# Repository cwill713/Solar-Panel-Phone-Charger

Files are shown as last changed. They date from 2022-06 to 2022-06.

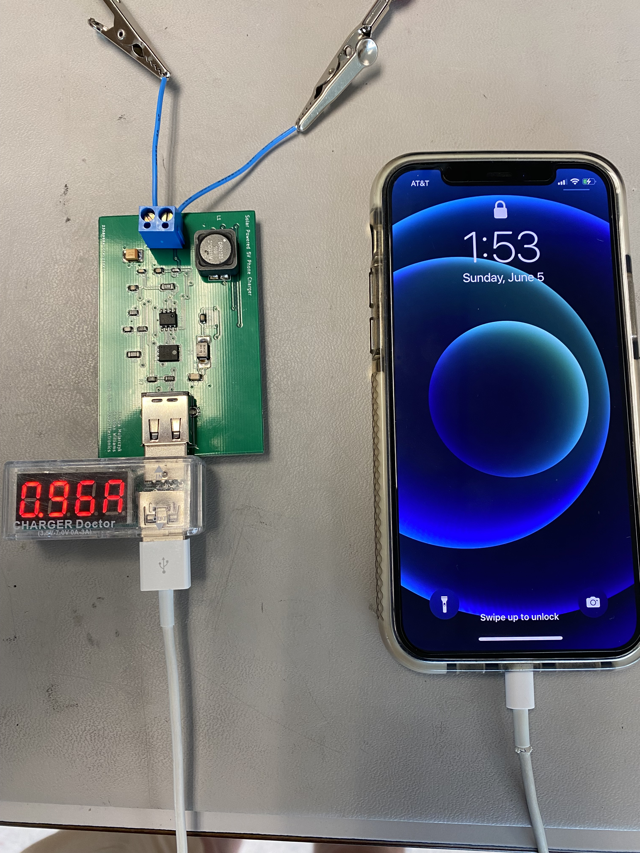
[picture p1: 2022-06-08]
Pictures/Output current to iphone.jpg

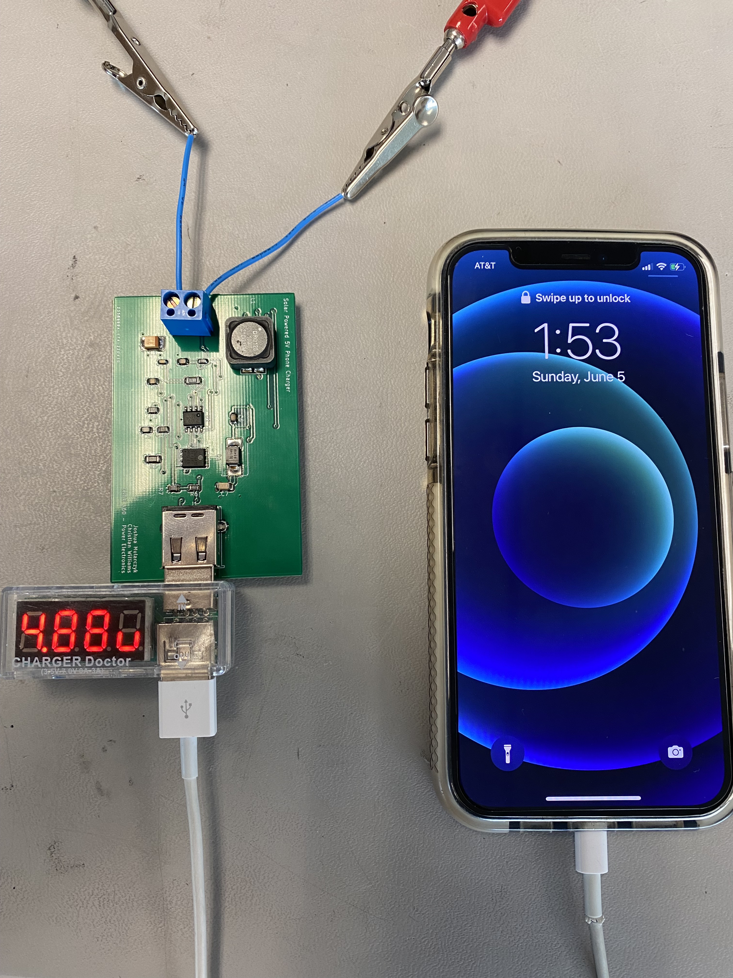
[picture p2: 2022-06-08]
Pictures/Output Voltage to iphone.jpg

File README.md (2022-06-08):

# Solar Smartphone Charger

This is the the project, assigned by [Dr. Rob Frohne](https://github.com/frohro), that [Joshua Mularczyk](https://github.com/JoshuaMularczyk) and I designed for our Power Electronics class. This project used our knowledge of power efficiency and stepping down voltage along with our knowledge of KiCAD and LTSpice to create our own portable solar phone charges. 

## Design Objectives:
- Output 5V from a higher input voltage
- Draw 1A at the output
- Inexpensive ($20-$30 Budget)
- AS efficient as possible

## Overview

Capture

Josh and I wanted to design a solar phone charger because we thought of the potential use of people who spend a lot of time outside. We also knew that Apple products need certain specifications to charge as oppose to Andriod products so we set out to figure out how to make our charger work for both.

The first simulation/schematic of our project allowed us to get the desired outputs, but we found that it was not very efficient, so we decided to redesign our board and end up with a new string of designs

The heart of our circuit is the [LM3478](https://www.ti.com/lit/ds/symlink/lm3478.pdf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) which is a high-efficiency low-side n-channel controller. This allows us to regulate any voltage between 2.39 and 40V that could come from our 10W solar panels

## Rev 7 Design

schematic2

This is the most recent KiCad schematic for our circuit design. Josh used the Texas Instrument [Webench Power Designer](https://www.ti.com/design-resources/design-tools-simulation/webench-power-designer.html) to generate this step-down circuit. The design specified a 5V to 12V input voltage based on the likely solar panel outputs. We also specified the a maximum of 1A should be be able to be drawn from our circuit.

## Rev 7 Simulation
sim
This is the complete simulation of our circuit. We can see here that at around 7ms, the output voltage of circuit is 5V

### Voltage Outputs (5V 2.7V 2V)
ThreeOutputVoltages

This is the simulation of the voltage dividers that shows the voltage going to our USB pins. V+, D+, and D-. This will be talked about more in the testing section.

### Input and Output Current
currentsim

This simulations shows us that we achieved the low input voltage that we need. The 5 Ohm resistor allowed us to simulate the current our phone would draw from the circuit. The output current of 1A will allow us to power our phone with 5W.

## Rev 7 PCB Design
pcb2

This is the PCB design of the board we sourced from [JLCPCB](https://jlcpcb.com/VGS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),

## Rev 6 Testing


Josh and I each constructed a our own boards and tested them. When testing the boards with a 0-18V 1A power supply, we found that the boards could charge Ti-84 calculators and Andriod phones, but not an iPhone. To see if we couldn't draw enough current from the power supply, we connected our board to 24V 3A power supply and saw the same results. After we performed some research, Josh found that we needed voltage across the D+ and D- pins, 2.7 and 2V respectivly. To achieve this, we created a votalde dividers using through-hole resistors and soldered them to the back of the boards. We then tested the boards and found that we were able to succesfully charge our iPhones.




After we tested the boards in the lab, we connected our boards to our solar panels and tested them outside. We found that we were getting around 4.8V and .96A at the output which gave us 4.61W at the output. 

## Rev 6 Results
The image on the left shows the voltage being supplied to the iPhone through the 24V 4A power suplies. The image on the right shows the current being drawn by the iPhone.



More images are avaialble in the [pictures](https://github.com/cwill713/Solar-Panel-Phone-Charger/tree/main/Pictures) folder. The video of testing made by Josh is availabel [here](https://youtu.be/SS7m2UqrDPg).

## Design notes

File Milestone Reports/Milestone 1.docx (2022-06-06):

Joshua Mularczyk and Christian Williams

ENGR 460

Milestone 1

4 April 2022

Project Definition

Project: Solar powered phone charger

Stretch Goal: Make it a wireless charger

Definition:

For our project this quarter, we have decided to design power electronics to use solar power to charge a smartphone. This will be done using solar panels that will provide charge to a external rechargeable battery (maybe 2 AA’s?) which will then run through circuitry that has some type of switch that shuts off the charging when the maximum voltage has been reached and circuitry to allow the power to pass from the batteries through a USB port so that a smart phone can be plugged in. If time allows, a casing can be designed for the circuitry using 3D printing for a final portable product.

References that sparked idea:

https://www.youtube.com/watch?v=OyslcihUtzQ

- Youtube video explaining how to create a DC to DC Boost Converter

https://www.instructables.com/Wireless-Solar-Charger/

- Project using solar panels to create a wireless charger for a smartphone

https://www.engineeringforchange.org/news/how-to-build-a-solar-powered-usb-charger-for-phones-and-other-small-devices/

- Shows the process of designing a similar solar powered phone charger

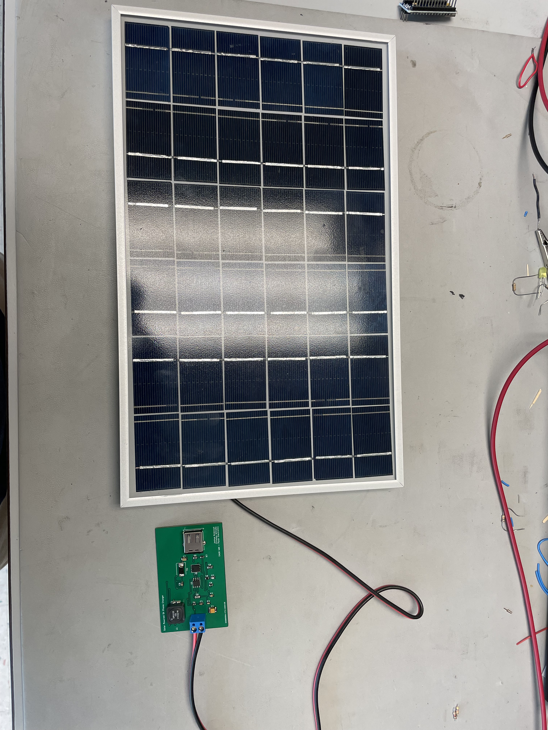
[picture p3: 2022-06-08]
Pictures/solar panel.jpg

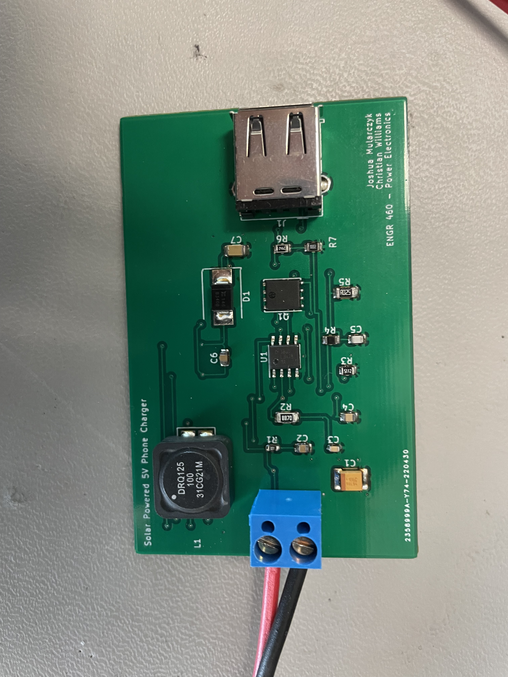
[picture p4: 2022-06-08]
Pictures/circuit board.jpg

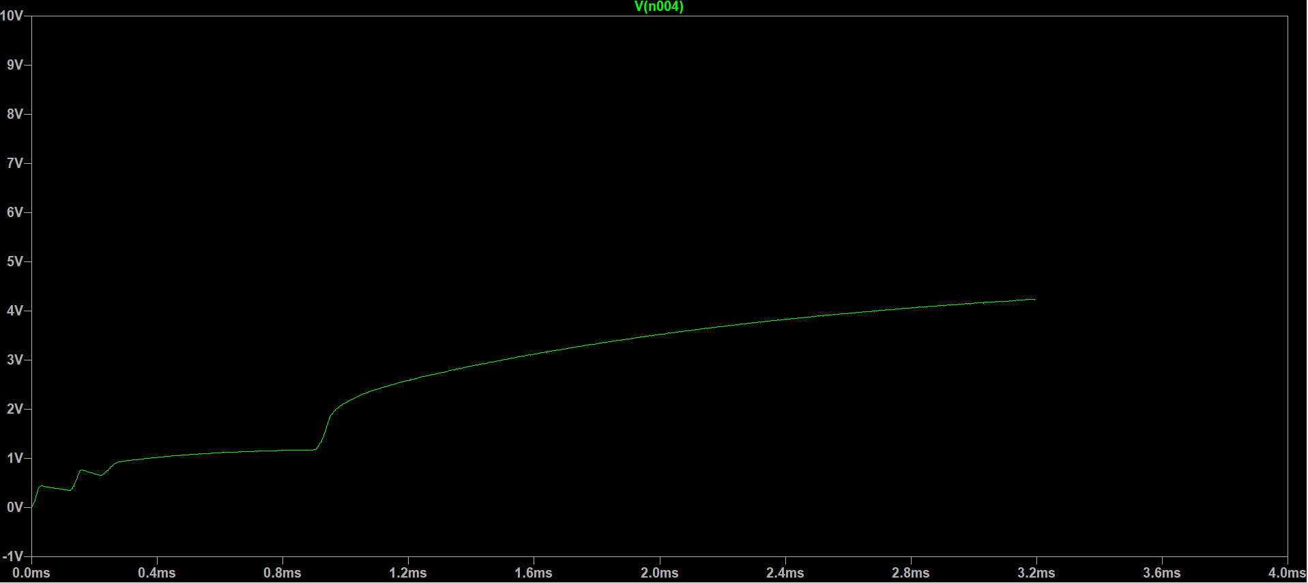
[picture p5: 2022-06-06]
Simulations/Pictures of Output Voltage/LoadResistorSimClose.PNG

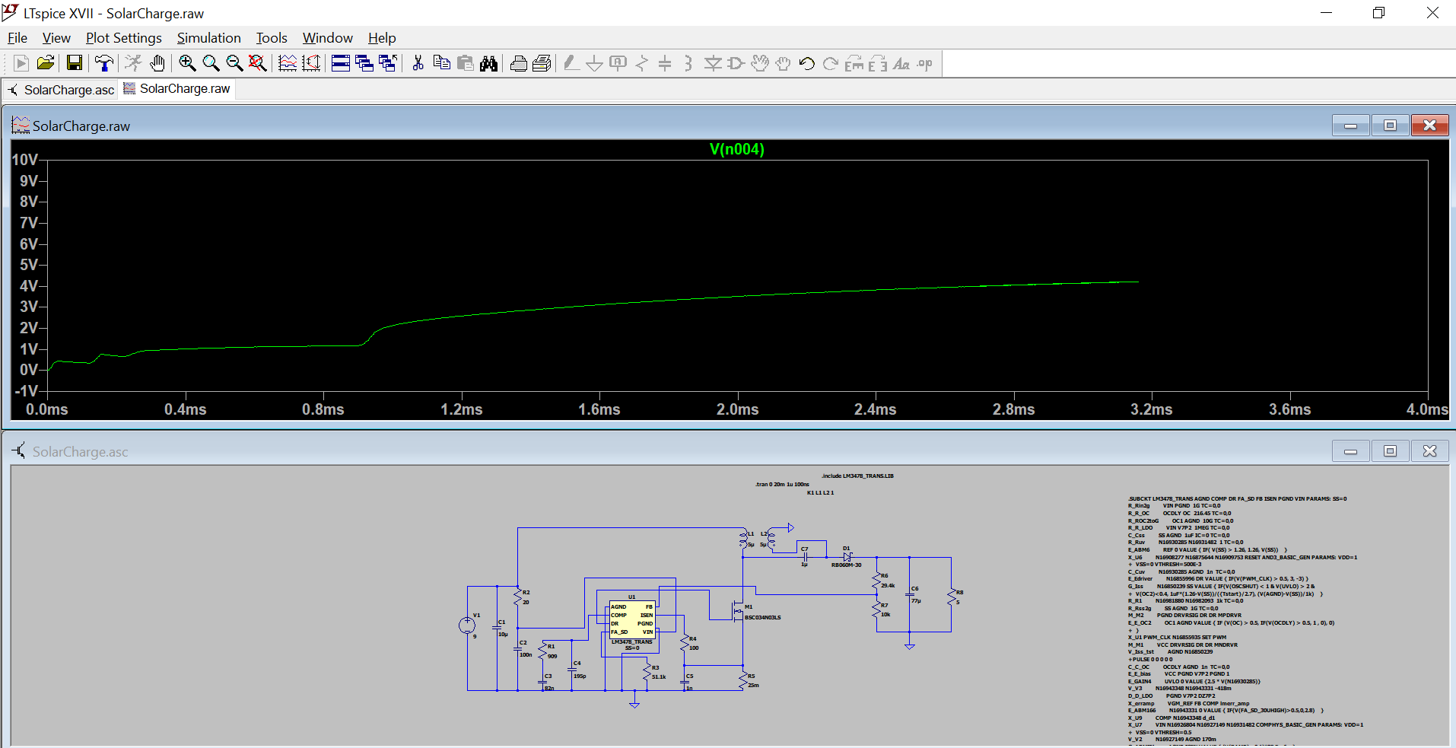
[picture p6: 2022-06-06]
Simulations/Pictures of Output Voltage/loadResistorSim.PNG

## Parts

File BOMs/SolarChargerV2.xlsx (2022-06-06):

Id | Label | Footprint | Amount | Value | Price | Supplier and ref
1 | Le | DRQ | 1 | 10u | $1.81 | https://www.digikey.com/en/products/detail/eaton-electronics-division/DRQ125-100-R/667233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
2 | C7 | Capacitor_SMD:C_1206_3216Metric | 1 | 47u | $0.74 | https://www.digikey.com/en/products/detail/murata-electronics/GRM31CR61A476KE15L/4359666
3 | C1 | Capacitor_SMD:C_1812_4532Metric | 1 | 10u | $0.45 | https://www.digikey.com/en/products/detail/kyocera-avx/TPSB106K016R0800/678477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
4 | C5 | Capacitor_SMD:C_0805_2012Metric | 1 | 1n | $0.10 | https://www.digikey.com/en/products/detail/walsin-technology-corporation/0805N102J500CT/9355088
5 | C3 | Capacitor_SMD:C_0603_1608Metric | 1 | 82n | $0.14 | https://www.digikey.com/en/products/detail/kyocera-avx/0603YC823KAT2A/563348
6 | C2 | Capacitor_SMD:C_0805_2012Metric | 1 | 100n | $0.10 | https://www.digikey.com/en/products/detail/w%C3%BCrth-elektronik/885012207045/5453900
7 | C4 | Capacitor_SMD:C_0805_2012Metric | 1 | 200p | $0.15 | https://www.digikey.com/en/products/detail/yageo/CC0805KRX7R9BB201/5884236
8 | C6 | Capacitor_SMD:C_0805_2012Metric | 1 | 1u | $0.19 | https://www.digikey.com/en/products/detail/murata-electronics/GRM21BR71C105MA01L/586691
9 | J1 | USB_A_Molex_67643_Horizontal | 1 | USB_A | $1.66 | https://www.digikey.com/en/products/detail/molex/0676430910/917619
10 | D1 | Diode_SMD:D_SMC | 1 | B340 | $0.54 | https://www.digikey.com/en/products/detail/diodes-incorporated/B340B-13-F/768869
11 | U1 | SOIC-8_3.9x4.9mm_P1.27mm | 1 | LM3478MA_NOPB | $2.95 | https://www.digikey.com/en/products/detail/texas-instruments/LM3478MA-NOPB/2682777
12 | Q1 | TDSON-8-1 | 1 | CSD16410Q5A | $1.01 | https://www.digikey.com/en/products/detail/texas-instruments/CSD16410Q5A/2038309
13 | R6 | Resistor_SMD:R_0805_2012Metric | 1 | 29.4k | $0.10 | https://www.digikey.com/en/products/detail/panasonic-electronic-components/ERJ-6ENF2942V/111566
14 | R4 | Resistor_SMD:R_0805_2012Metric | 1 | 100 | $1.63 | https://www.digikey.com/en/products/detail/vishay-dale/M55342K06B100DRS3/2941801
15 | R3 | Resistor_SMD:R_0805_2012Metric | 1 | 51.1k | $0.10 | https://www.digikey.com/en/products/detail/yageo/RC0805FR-0751K1L/728015
16 | R1 | Resistor_SMD:R_0603_1608Metric | 1 | 20 | $0.10 | https://www.digikey.com/en/products/detail/yageo/RC0603FR-0720RL/727039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
17 | R7 | Resistor_SMD:R_0805_2012Metric | 1 | 10k | $0.10 | https://www.digikey.com/en/products/detail/stackpole-electronics-inc/RNCP0805FTD10K0/2240262
18 | R5 | Resistor_SMD:R_1206_3216Metric | 1 | 25m | $0.49 | https://www.digikey.com/en/products/detail/stackpole-electronics-inc/CSR1206FK25L0/1646093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
19 | R2 | Resistor_SMD:R_1206_3216Metric | 1 | 887 | $0.20 | https://www.digikey.com/en/products/detail/panasonic-electronic-components/ERJ-8ENF8870V/88853
20 | SC1 | SIP-2 | 1 | Solar_Cell | $17.99 | amazon.com/dp/B00OZC19AY/ref=emc_bcc_2_i?th=1 (https://www.amazon.com/Treedix-Polysilicon-Polycrystalline-Encapsulated-Waterproof/dp/B0834MQDT8)
 |  |  |  | Total Cost | $30.55 | cart | https://www.digikey.com/short/1jf4t9wm

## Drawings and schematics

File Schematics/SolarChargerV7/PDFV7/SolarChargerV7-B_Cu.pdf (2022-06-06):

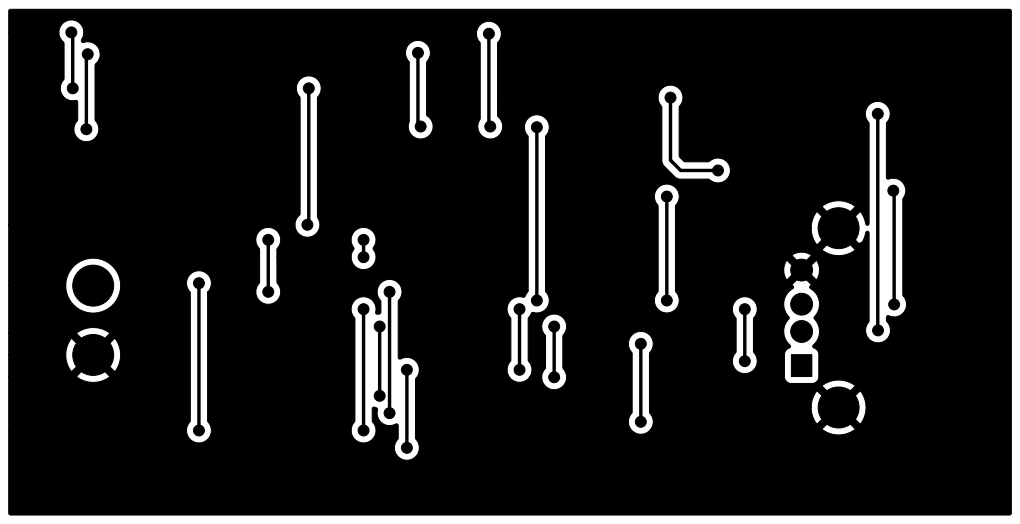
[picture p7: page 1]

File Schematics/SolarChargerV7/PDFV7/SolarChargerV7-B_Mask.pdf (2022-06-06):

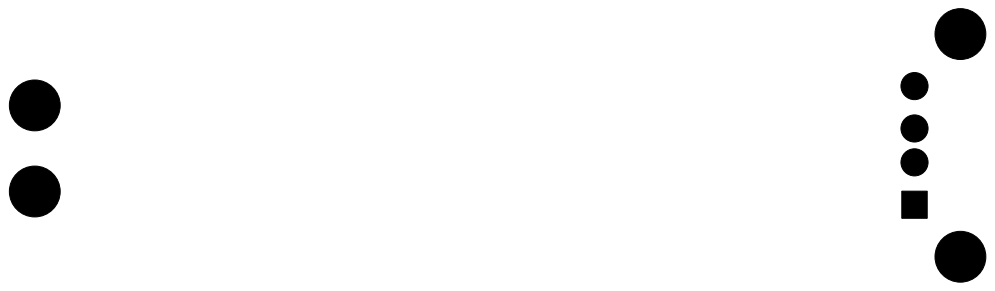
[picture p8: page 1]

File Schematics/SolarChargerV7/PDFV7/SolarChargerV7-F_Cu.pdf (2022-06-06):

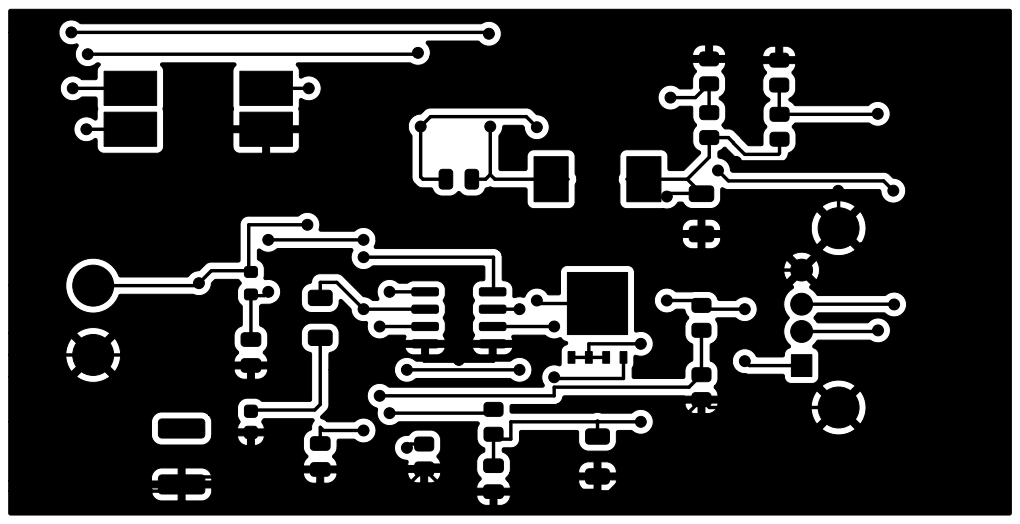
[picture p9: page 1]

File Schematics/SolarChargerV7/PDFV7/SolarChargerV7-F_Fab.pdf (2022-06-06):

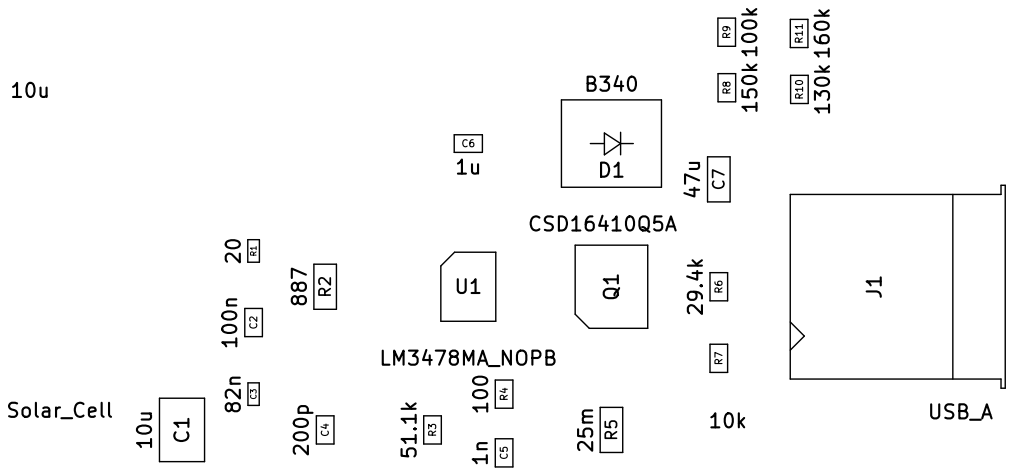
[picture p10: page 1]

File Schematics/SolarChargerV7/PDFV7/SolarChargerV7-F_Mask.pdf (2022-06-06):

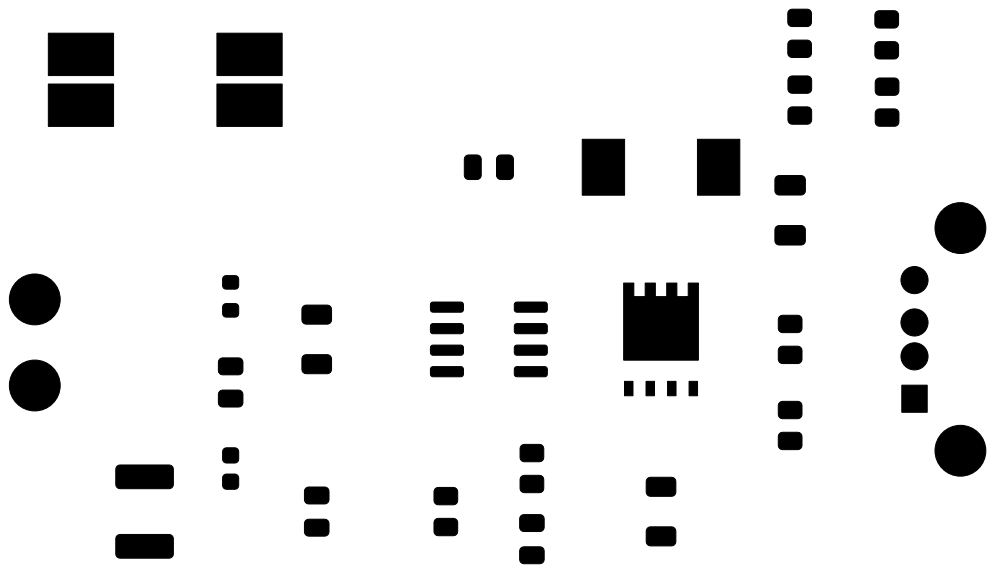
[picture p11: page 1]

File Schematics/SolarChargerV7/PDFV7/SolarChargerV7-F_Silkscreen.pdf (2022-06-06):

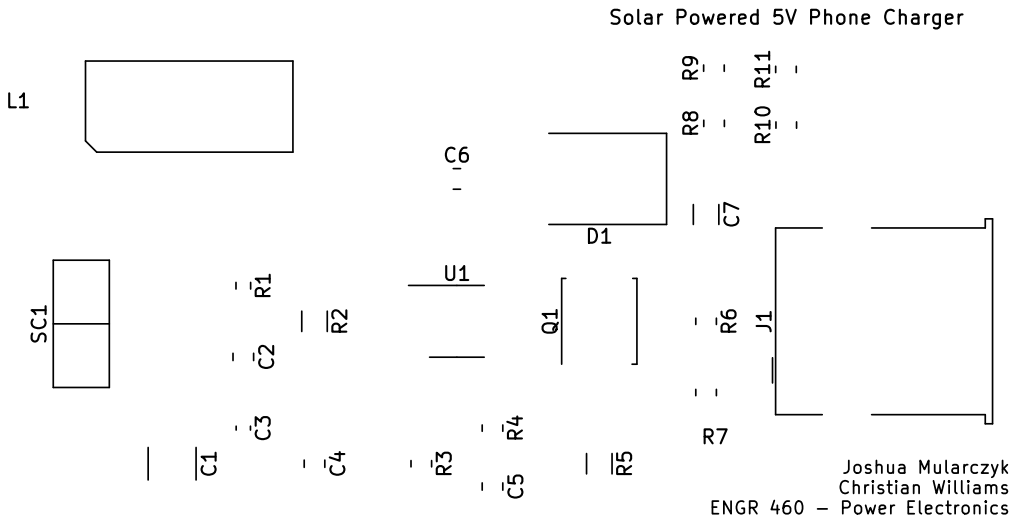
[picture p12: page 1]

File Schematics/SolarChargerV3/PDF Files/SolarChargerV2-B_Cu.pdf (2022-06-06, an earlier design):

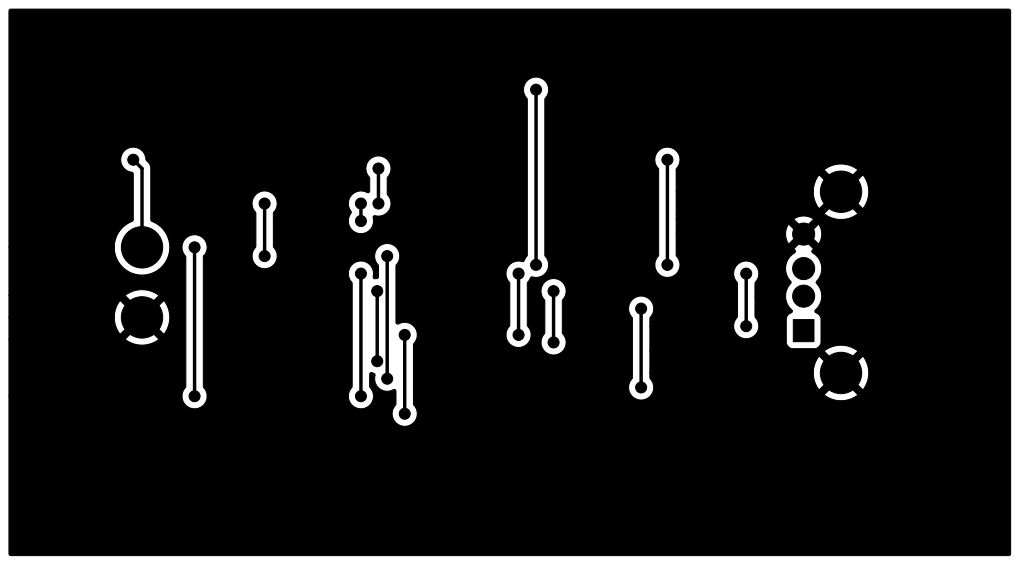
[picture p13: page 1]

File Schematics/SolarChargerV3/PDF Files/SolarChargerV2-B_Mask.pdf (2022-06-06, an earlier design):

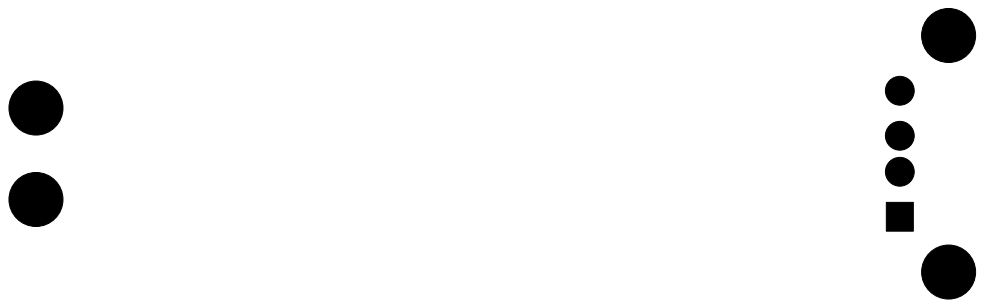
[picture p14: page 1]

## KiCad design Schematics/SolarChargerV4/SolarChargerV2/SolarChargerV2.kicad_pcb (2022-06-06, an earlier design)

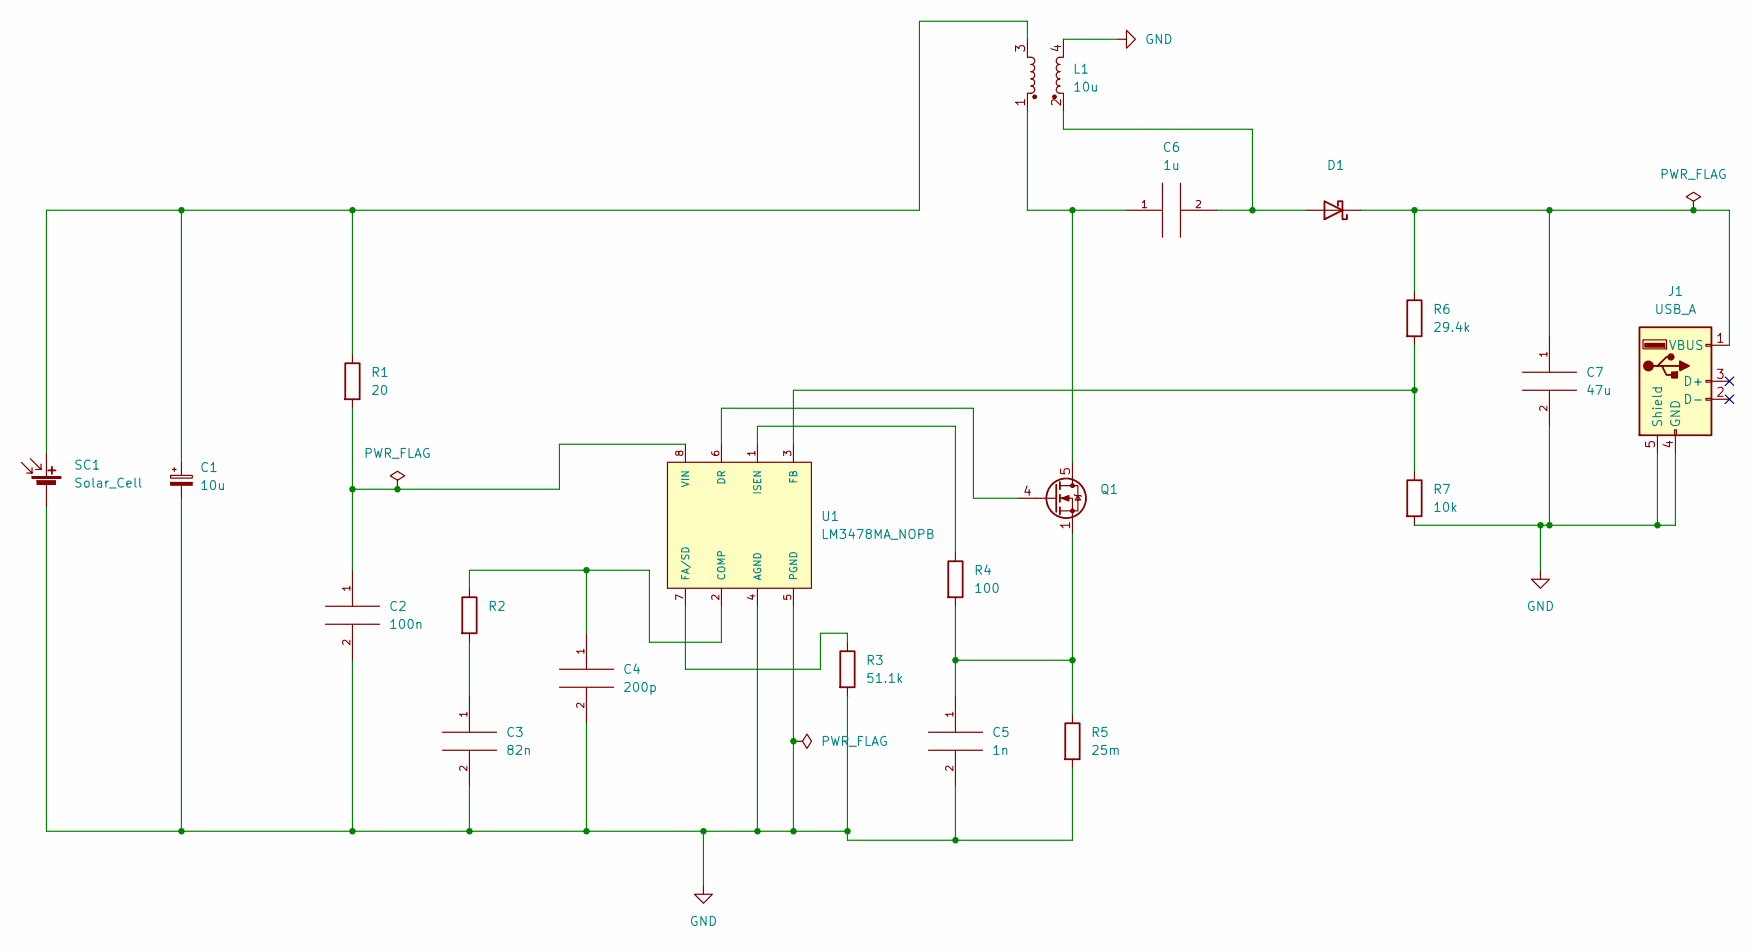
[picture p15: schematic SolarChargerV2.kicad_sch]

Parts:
C1: 10u; CP_Elec_3x5.3
C2: 100n; C_0603_1608Metric_Pad1.08x0.95mm_HandSolder
C3: 82n; C_0603_1608Metric_Pad1.08x0.95mm_HandSolder
C4: 200p; C_1812_4532Metric_Pad1.57x3.40mm_HandSolder
C5: 1n; C_0603_1608Metric_Pad1.08x0.95mm_HandSolder
C6: 1u; C_2220_5650Metric_Pad1.97x5.40mm_HandSolder
C7: 47u; CP_Elec_3x5.3
D1: (no value)
J1: USB_A; USB_A_Molex_67643_Horizontal
L1: 10u; DRQ
Q1: (no value)
R1: 20; R_0603_1608Metric_Pad0.98x0.95mm_HandSolder
R2: (no value)
R3: 51.1k; R_0603_1608Metric_Pad0.98x0.95mm_HandSolder
R4: 100; R_0603_1608Metric_Pad0.98x0.95mm_HandSolder
R5: 25m; R_2816_7142Metric_Pad3.20x4.45mm_HandSolder
R6: 29.4k; R_0603_1608Metric_Pad0.98x0.95mm_HandSolder
R7: 10k; R_0805_2012Metric
SC1: Solar_Cell; SIP-2
U1: LM3478MA_NOPB; SOIC-8_3.9x4.9mm_P1.27mm

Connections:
GND: C1.2, C2.2, C3.2, C4.2, C5.2, C7.2, J1.4 (GND), J1.5 (Shield), L1.4, R3.2, R5.2, R7.2, SC1.2 (-), U1.4 (AGND), U1.5 (PGND)
unnamed: C1.1, L1.3, R1.1, SC1.1 (+)
unnamed: C2.1, R1.2, U1.8 (VIN)
unnamed: C3.1, R2.2
unnamed: C4.1, R2.1, U1.2 (COMP)
unnamed: C5.1, Q1.1 (S), Q1.2 (S), Q1.3 (S), R4.2, R5.1
unnamed: C6.2, D1.2 (A), L1.2
unnamed: C7.1, D1.1 (K), J1.1 (VBUS), R6.1
unnamed: C6.1, L1.1, Q1.5 (D)
unnamed: R3.1, U1.7 (FA/SD)
unnamed: R4.1, U1.1 (ISEN)
unnamed: R6.2, R7.1, U1.3 (FB)
unnamed: Q1.4 (G), U1.6 (DR)

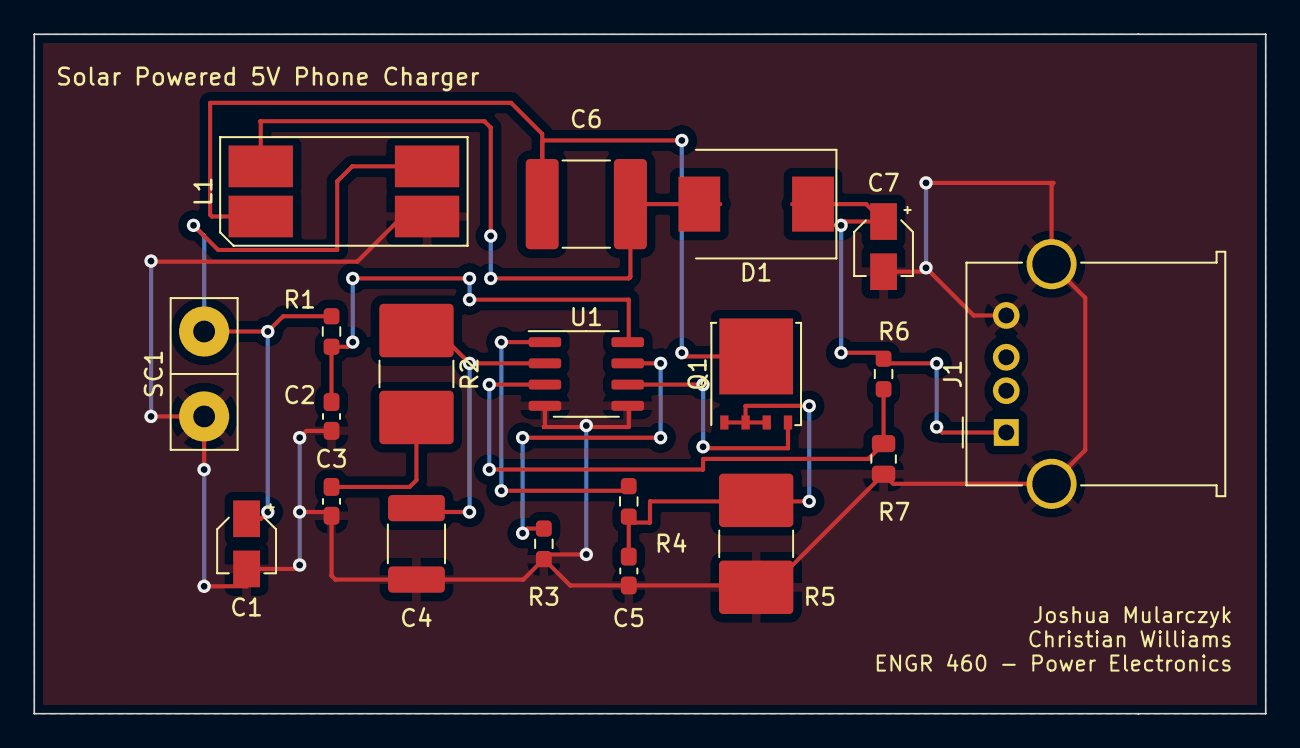
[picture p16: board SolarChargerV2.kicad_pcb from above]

Board: 2 copper layers, 73.7 x 40.6 mm, 20 parts (0 on the bottom side), 13 nets.

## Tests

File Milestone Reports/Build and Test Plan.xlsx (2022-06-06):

Build and Test Plan | Testers: Joshua Mularczyk and Christian Williams
Steps: | Description: | Column3 | Column4 | Column5 | Column6 | Column7 | Column8 | Column9 | Column10 | Column11 | Column12
1 | Unbox and Take Inventory of Parts from Digikey and Amazon
2 | Designate Storage area (Analog Lab)
3 | Take Solar Panel outside and test: Output Voltage(open Circuit), Output Current(short circuit), maximum power point (using a resistor(Voc/Isc) to best represent our load, and Calculate Output Power | Expected Voltage: 9V | Expected Current: 1.1 Amps | Expected Power: 10W
4 | Construct the Circuit by soldering onto PCB
5 | Inspect all solder connection under the Microscope to check for errors
6 | Check any parts with ohm meter
7 | Plug in power souce and watch current (if it peggs out then immediately shut it off
8 | Turn on the power source again and check output voltage by using the through hole connections before soldering on the USB connector and a load resistor.
9 | If output voltage is at or near 5V then go though and check any other values.
10 | Solder on solar panel
